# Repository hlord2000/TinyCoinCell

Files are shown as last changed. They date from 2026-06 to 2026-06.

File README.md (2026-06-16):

# TinyCoinCell

TinyCoinCell is a compact KiCad reference design for a coin-cell powered
Nordic beacon built around the nRF54L15, optional nPM2100 primary-cell PMIC,
and an ADXL367 accelerometer.

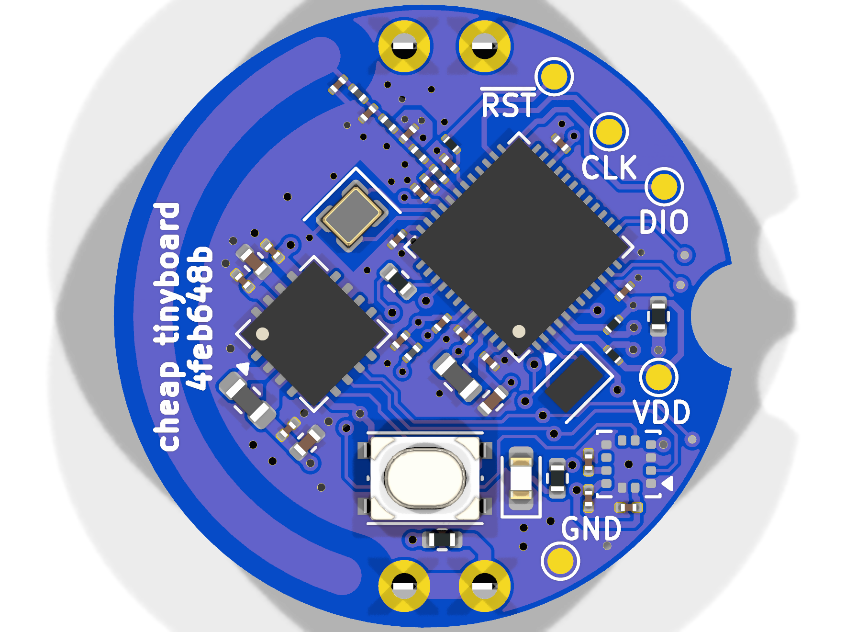
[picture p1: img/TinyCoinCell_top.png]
TinyCoinCell top render


## Hardware

- nRF54L15 low-power Bluetooth LE 6 SoC, 1.5 MB NVM, 256 KB RAM, Arm Cortex-M33,
  and RISC-V coprocessor
- Optional nPM2100 primary-cell PMIC with fuel gauge and hibernate support
- ADXL367 ultralow-power accelerometer on I2C
- CR2032 battery holder
- User button and user LED
- SWD programming pads and UART breakout pads
- 32 MHz HF crystal and 32.768 kHz LF crystal

## Assembly Variants

| Variant | Populate | Do not populate | Notes |
| --- | --- | --- | --- |
| `nPM2100` | `U8`, `C44-C47`, `C49`, `L6`, `R3` | `R4`, `R7` | Button is connected to the nPM2100 ship-button input. The host can observe it through `nPM2100.GPIO0` on `P1.05`. |
| `No nPM2100` | `R4`, `R7` | `U8`, `C44-C47`, `C49`, `L6`, `R3` | Battery powers the board directly and the user button is connected to `P1.11`. |

Both variants omit the test pads from production placement files. The KiCad
variants also override `R5` and `R6` to `4.7kR`.

## Pinout

| Function | nRF54L15 pin |
| --- | --- |
| User LED | `P1.02` |
| I2C SDA | `P1.03` |
| I2C SCL | `P1.04` |
| nPM2100 GPIO0 | `P1.05` |
| User button, no-nPM2100 variant | `P1.11` |
| UART TX | `P2.00` |
| UART RX | `P2.02` |

This project uses symbols and footprints from
[nordic-lib-kicad](https://github.com/hlord2000/nordic-lib-kicad)

## Release Artifacts

The `v2` release is built from the contents of the local `build/` directory.
It includes the rendered board images, schematic PDF, STEP model, Gerbers, BOMs,
placement files, KiCad ERC/DRC reports, and the generated design-review bundle.

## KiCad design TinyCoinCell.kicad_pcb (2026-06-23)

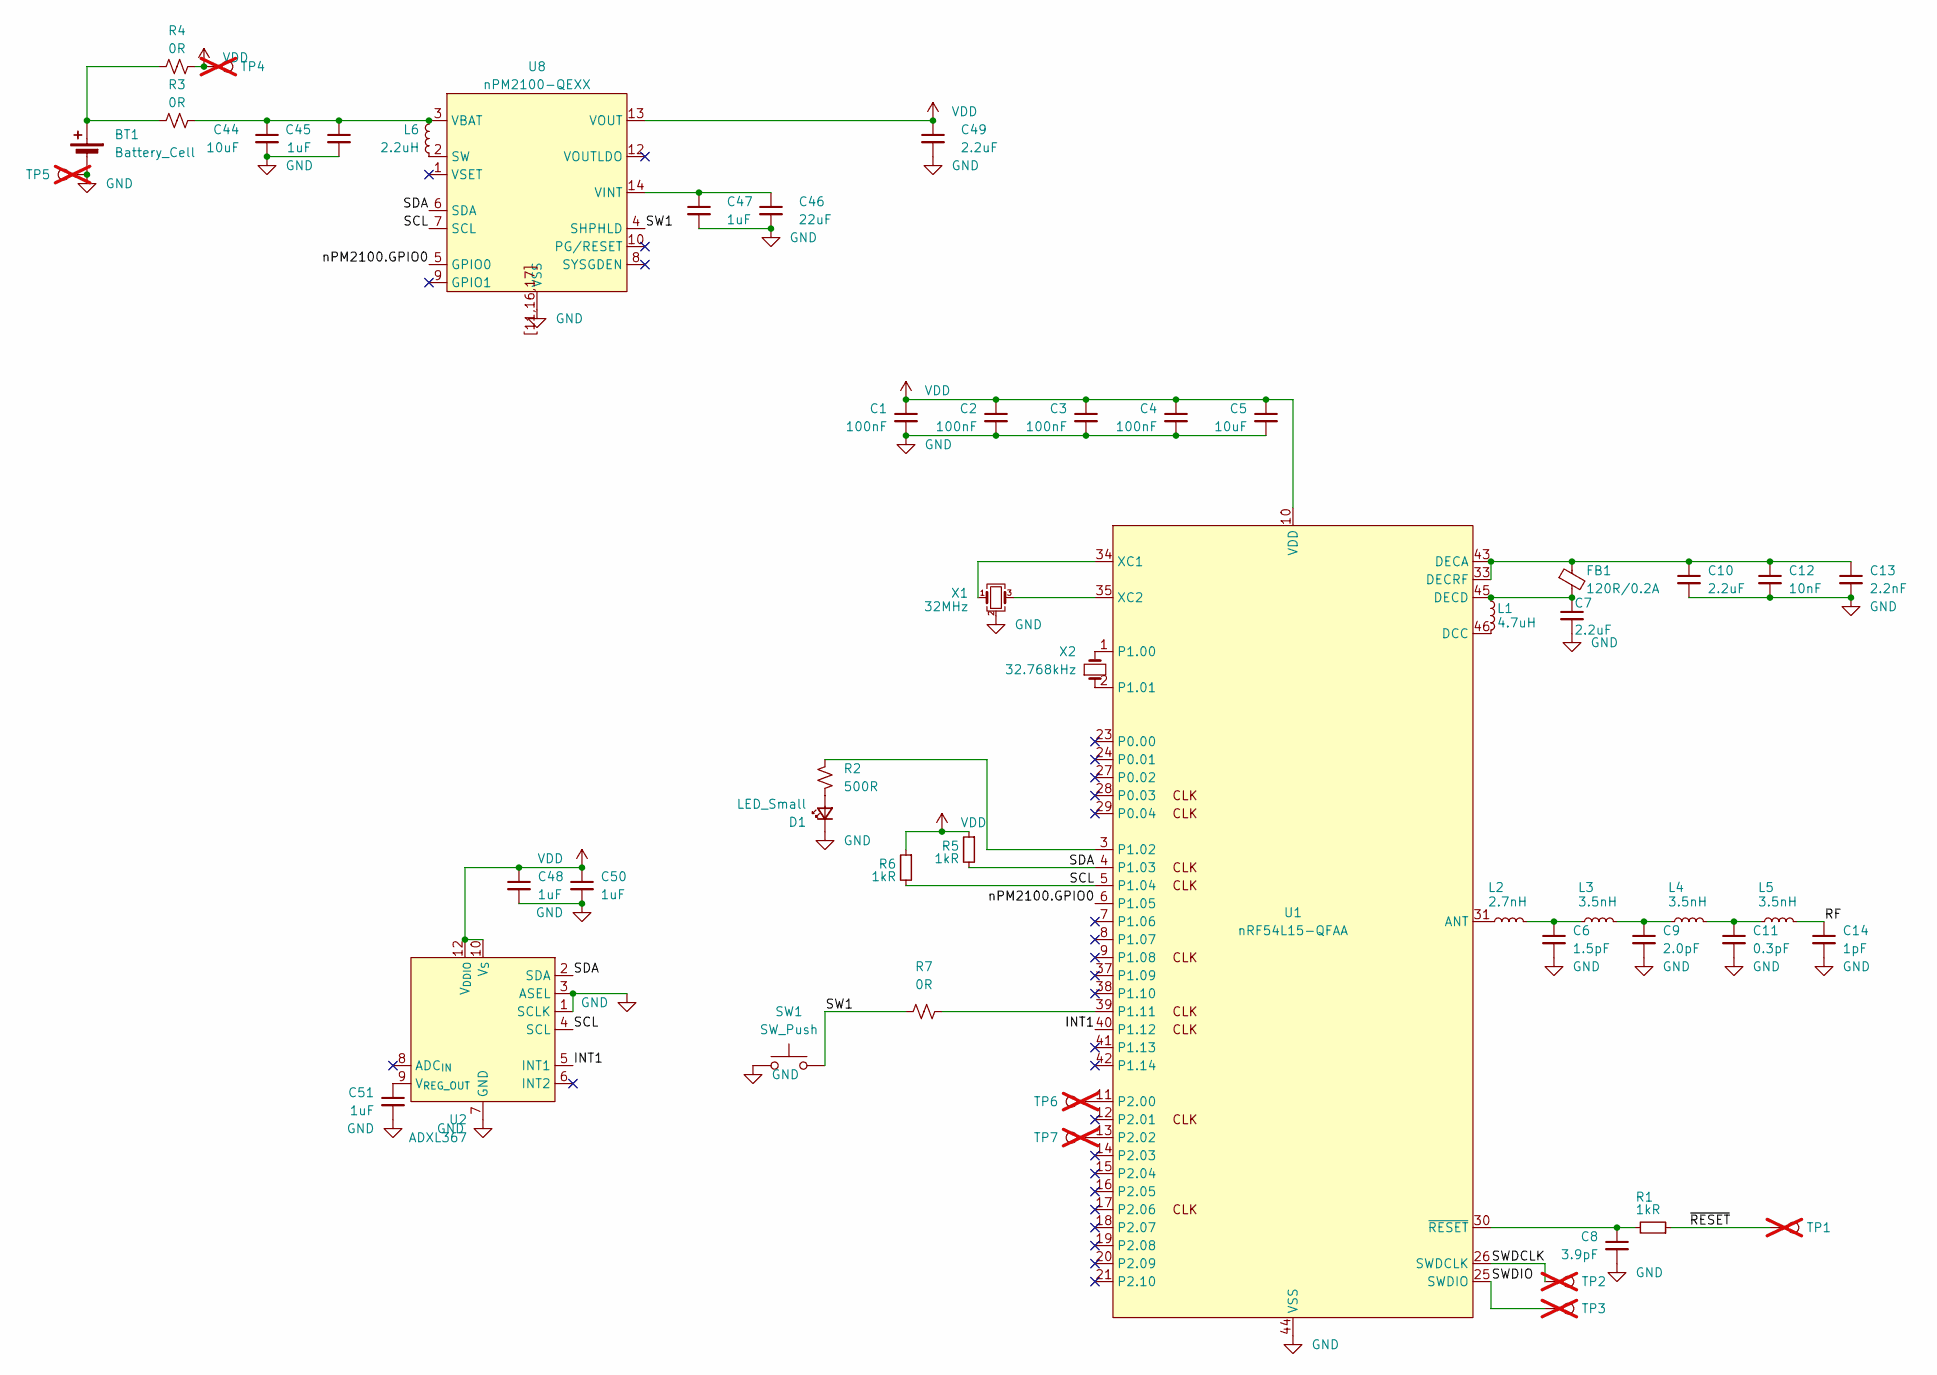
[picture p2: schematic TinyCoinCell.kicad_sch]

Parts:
BT1: Battery_Cell; BAT-TH_BAT-HLD-001-THM_1; LCSC C22417572
C1, C2, C3, C4: 100nF; C_0201_0603Metric_L; LCSC C2903664
C5: 10uF; C_0402_1005Metric_L; LCSC C15525
C6: 1.5pF; C_0201_0603Metric_L; LCSC C18164554
C7, C10: 2.2uF; C_0201_0603Metric_L; LCSC C5377657
C8: 3.9pF; C_0201_0603Metric_L; LCSC C18164580
C9: 2.0pF; C_0201_0603Metric_L; LCSC C18164556
C11: 0.3pF; C_0201_0603Metric_L; LCSC C723329
C12: 10nF; C_0201_0603Metric_L; LCSC C7393836
C13: 2.2nF; C_0201_0603Metric_L; LCSC C5142540
C14: 1pF; C_0201_0603Metric_L; LCSC C723329
C44: 10uF; C_0402_1005Metric; LCSC C15525
C45, C47, C48, C50, C51: 1uF; C_0201_0603Metric; LCSC C76930
C46: 22uF; C_0402_1005Metric; LCSC C385994
C49: 2.2uF; C_0201_0603Metric; LCSC C319184
D1: LED_Small; LED_0603_1608Metric; LCSC C52675989
FB1: 120R/0.2A; L_0201_0603Metric_L; LCSC C97850
L1: 4.7uH; L_0603_1608Metric_L; LCSC C295681
L2: 2.7nH; L_0201_0603Metric_L; LCSC C370148
L3, L4, L5: 3.5nH; L_0201_0603Metric_L; LCSC C52109755
L6: 2.2uH; L_0603_1608Metric; LCSC C394950
R1, R5, R6: 1kR; R_0201_0603Metric_L; LCSC C102683
R2: 500R; R_0402_1005Metric; LCSC C4125
R3, R4, R7: 0R; R_0402_1005Metric; LCSC C17168
SW1: SW_Push; SW_Push_1P1T_NO_Vertical_Wuerth_434133025816; LCSC C139797
TP1, TP2, TP3, TP4, TP5, TP6, TP7: TestPoint; TestPoint_Pad_D1.0mm; not fitted
U1: nRF54L15-QFAA; QFN-48-1EP_6x6mm_P0.4mm_EP4.6x4.6mm_ThermalVias; LCSC C42458750
U2: ADXL367; ADXL367_LGA-12_2.11x2.21mm_P0.5mm_LayoutBorder2x4y; LCSC C7424127
U8: nPM2100-QEXX; UQFN-16-1EP_4x4mm_P0.65mm_EP2.6x2.6mm_ThermalVias; LCSC C46968654
X1: 32MHz; Crystal_SMD_2016-4Pin_2.0x1.6mm; LCSC C2965582
X2: 32.768kHz; Crystal_SMD_2012-2Pin_2.0x1.2mm; LCSC C2838163

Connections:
/INT1: U1.40 (P1.12), U2.5 (INT1)
/RF: C14.1, L5.2
/SCL: R6.2, U1.5 (P1.04), U2.4 (SCL), U8.7 (SCL)
/SDA: R5.2, U1.4 (P1.03), U2.2 (SDA), U8.6 (SDA)
/SW1: R7.2, SW1.1, U8.4 (SHPHLD)
/SWDCLK: TP2.1 (1_1), U1.26 (SWDCLK)
/SWDIO: TP3.1 (1_1), U1.25 (SWDIO)
/nPM2100.GPIO0: U1.6 (P1.05), U8.5 (GPIO0)
/~RESET: R1.1, TP1.1 (1_1)
GND: BT1.2 (-), C1.2, C2.2, C3.2, C4.2, C5.2, C6.2, C7.2, C8.2, C9.2, C10.2, C11.2, C12.2, C13.2, C14.2, C44.2, C45.2, C46.2, C47.2, C48.2, C49.2, C50.2, C51.2, D1.1 (K), SW1.2, TP5.1 (1_1), U1.32 (VSS_PA), U1.44 (VSS), U1.49 (VSS), U2.1 (SCLK), U2.3 (ASEL), U2.7 (GND), U2.11 (GND), U8.11 (VSS), U8.16 (VSS), U8.17 (VSS), U8.[11,16,17] (VSS), X1.2 (G), X1.4 (G)
unnamed: BT1.1 (+), R3.1, R4.1
unnamed: C6.1, L2.2, L3.1
unnamed: C9.1, L3.2, L4.1
unnamed: C11.1, L4.2, L5.1
unnamed: C46.1, C47.1, U8.14 (VINT), U8.15 (VINT)
unnamed: D1.2 (A), R2.2
unnamed: L2.1, U1.31 (ANT)
unnamed: L1.2, U1.46 (DCC)
unnamed: C10.1, C12.1, C13.1, FB1.1, U1.33 (DECRF), U1.43 (DECA)
unnamed: C7.1, FB1.2, L1.1, U1.45 (DECD)
unnamed: U1.1 (P1.00), X2.2
unnamed: U1.2 (P1.01), X2.1
unnamed: R2.1, U1.3 (P1.02)
unnamed: R7.1, U1.39 (P1.11)
unnamed: TP6.1 (1_1), U1.11 (P2.00)
unnamed: TP7.1 (1_1), U1.13 (P2.02)
unnamed: U1.34 (XC1), X1.1
unnamed: U1.35 (XC2), X1.3
unnamed: C8.1, R1.2, U1.30 (~RESET)
unnamed: C51.1, U2.9 (V_{REG_OUT})
unnamed: L6.2, U8.2 (SW)
unnamed: C44.1, C45.1, L6.1, R3.2, U8.3 (VBAT)
VDD: C1.1, C2.1, C3.1, C4.1, C5.1, C48.1, C49.1, C50.1, R4.2, R5.1, R6.1, TP4.1 (1_1), U1.10 (VDD), U1.22 (VDD), U1.36 (VDD), U1.47 (VDD), U1.48 (VDD), U2.10 (V_{S}), U2.12 (V_{DDIO}), U8.13 (VOUT)

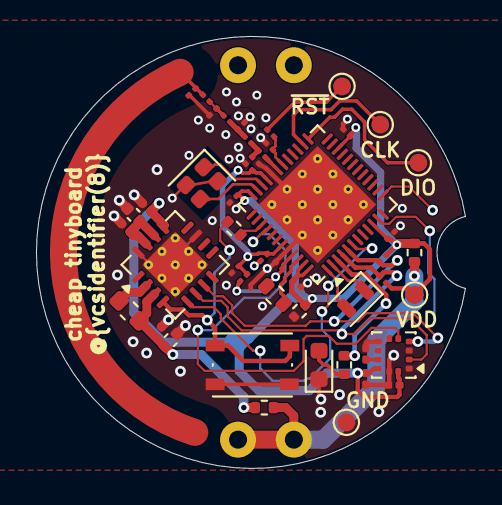
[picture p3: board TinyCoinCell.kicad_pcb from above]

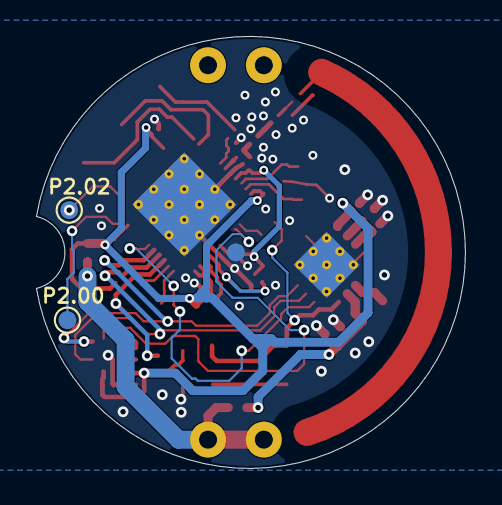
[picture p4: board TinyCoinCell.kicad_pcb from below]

Board: 4 copper layers, 23.8 x 24.0 mm, 51 parts (3 on the bottom side), 33 nets.

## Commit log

2026-06-03 Initial commit.
    [TinyCoinCell.kicad_pcb, TinyCoinCell.kicad_sch]
2026-06-03 Updated with BOM
    [TinyCoinCell.kicad_pcb, TinyCoinCell.kicad_sch]
2026-06-13 Updates for nPM2100
    [TinyCoinCell.kicad_pcb, TinyCoinCell.kicad_sch]
2026-06-16 Update for nPM2100, ADXL367
    [TinyCoinCell.kicad_pcb, TinyCoinCell.kicad_sch]
2026-06-16 Document TinyCoinCell v2 release
    [TinyCoinCell.kicad_pcb]
2026-06-16 Updated PCB
    [TinyCoinCell.kicad_pcb]
2026-06-16 Use local README board image
2026-06-23 Updates for manufacturing
    [TinyCoinCell.kicad_pcb, TinyCoinCell.kicad_sch]
